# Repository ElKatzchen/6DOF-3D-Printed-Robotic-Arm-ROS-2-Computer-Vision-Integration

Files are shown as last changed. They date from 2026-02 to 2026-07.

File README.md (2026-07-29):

# 6DOF 3D-Printed Robotic Arm: ROS 2 & Computer Vision Integration

This repository contains all the necessary data to fabricate, control, and modify a **6-Degree-of-Freedom (6DOF) robotic arm**. The project combines 3D printing, advanced CAD modeling, and a distributed control system using ROS 2.

## 🚀 Overview

The system is designed for **real-time teleoperation** via computer vision. It tracks a user's hand movements in a dedicated vision area and translates those coordinates into precise robotic motion using inverse kinematics.

### Key Features:
* **Mechanical Design:** All components are 3D-printable and were fully modeled in **SolidWorks 2025**. Original design files are included for easy modification.
* **Communication Stack:** Powered by **ROS 2 Humble**, enabling seamless distributed processing between a **PC** (high-level processing) and a **Raspberry Pi** (hardware abstraction).
* **Computer Vision:** Utilizes a dual-camera setup to track hand **keypoints** (Mediapipe-based).
* **Inverse Kinematics (IK):** The system captures the $XYZ$ coordinates of the user's index finger and maps them from the "Vision Space" to the "Robot Workspace," calculating the required joint angles in real-time.

---

## 📋 Prerequisites

Before you begin, ensure you have the following software and tools installed:

### **CAD & Hardware Design**
* **SolidWorks 2025**: Required to open or modify the original `.SLDPRT` and `.SLDASM` files.
* **3D Printer Slicer**: (e.g., Ultimaker Cura or PrusaSlicer) for processing the STL files.

### **Software & Robotics OS**
* **Ubuntu 22.04 LTS**: The recommended OS for stable ROS 2 Humble integration.
* **ROS 2 Humble Hawksbill**: The primary communication middleware.
* **Python 3.10+**: For vision and kinematics scripts.

### **Computer Vision & Libraries**
To run the hand-tracking and coordinate transformation nodes, you will need:
* **OpenCV**: For image processing.
* **MediaPipe**: For hand keypoint detection and tracking.
* **NumPy**: For matrix operations and inverse kinematics calculations.

---

## 📂 Repository Structure

The repository is organized into several folders:
* `/3D-Printed_Files`: Includes STL files for printing and SolidWorks 2025 source files.
* `/Inverse_Kinematics_Codes`: Includes all necesary codes for the inverse kinematics programming.
* `/ROS2_System`: The ROS 2 workspace containing the packages for robot description and control.
* `/Vision_System`: Python scripts for dual-camera hand tracking and coordinate mapping.

---

## 🛠️ Future Work

* Add 360 degrees motors and a closed loop control system
* Integrate Move It 2
* Integrate Reinforcement Learning on the Vision System

---

## 📌 Current Status: v3.0.0
* **Current Version:** 3.0.0
* **Last Update:** June 2026
* **Stable Version:** 3.0.0

---

**Author:** [Katzchen]

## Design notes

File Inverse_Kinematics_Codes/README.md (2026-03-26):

# 📐 Inverse Kinematics & Control System

This folder contains the core logic for calculating joint angles and the communication bridge between the high-level Python processing and the low-level hardware control.

## 🧠 Kinematics Engine (Python)

The main script handles the mathematical transformation from Cartesian coordinates $(X, Y, Z)$ to joint angles $(\theta_1 ... \theta_6)$.

* **IK Solver:** A Python-based script that calculates required angles in real-time.
* **Communication:** Data is transmitted via **UART** (Serial) to the microcontroller.
* **Software Safety Layer:** The script includes a pre-transmission validation check. It prevents the system from sending commands that exceed the mechanical limits of the arm or positions that are mathematically unreachable (Singularities).

---

## 🎮 Hardware Control (ESP32 / Arduino)

The low-level control is designed for an **ESP32 (30-pin version)**. This folder includes two distinct firmware options:

### 1. Home Calibration Script (`home_setup.ino`)
A standalone script used for initial calibration. When executed, it moves all servos to their "Home" or "Rest" positions. This is essential for verifying mechanical alignment before running full autonomous control.

### 2. UART Receiver & Servo Controller (`main_controller.ino`)
This script works in tandem with the Python IK solver. It listens for incoming angle data via UART and maps it to the servo PWM signals.
* **Redundant Safety System:** To ensure system reliability, the ESP32 performs a secondary validation on all incoming data. If a received angle is outside the physical range of the motors, the command is ignored or clamped, preventing hardware damage.

---

## 🛠️ Control Workflow

1.  **Vision Input:** Hand coordinates are captured.
2.  **IK Calculation:** Python computes the angles.
3.  **Safety Check 1:** Python validates the reachable workspace.
4.  **UART Transmission:** Angles are sent to the ESP32.
5.  **Safety Check 2:** ESP32 verifies signal integrity and physical limits.
6.  **Actuation:** Servos move to the validated positions.

---

## 📌 Pinout & Hardware Notes (ESP32)
* **UART RX/TX:** Ensure common ground between the PC/Raspberry Pi and the ESP32.
* **Power Supply:** Use an external power source for the servos (don't power 7 servos directly from the ESP32). The power supply used is 5VDC 10A.

**Next Step:** For details on how the coordinates are captured, see the [**ROS2 System**](../ROS2_System) documentation.

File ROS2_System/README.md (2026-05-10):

# 🤖 ROS 2 Workspace: Distributed Control System

This folder contains the **ROS 2 Humble** packages and nodes that manage communication, image streaming, and coordinate processing between the **Raspberry Pi** and the **Workstation (PC)**.

## 🏗️ System Architecture

The project follows a distributed architecture with **4 main nodes** designed to minimize latency and optimize processing power:

### 📡 Raspberry Pi Nodes (Edge)
* **Camera Publishers (2 Nodes):** These nodes capture real-time video streams from the dual-camera setup and publish them as compressed image topics to the network.
* **Servo Subscriber (1 Node):** This node listens for the calculated joint angles sent from the PC. Once received, it forwards the data via **UART** to the ESP32 microcontroller for physical actuation.

### 🖥️ Workstation Node (Central Processing)
* **Vision & IK Processor (1 Publisher/Subscriber Node):** This is the "brain" of the ROS 2 network.
    * **Subscribes** to the raw image topics from the Raspberry Pi.
    * **Processes** the images to extract hand keypoints and XYZ coordinates.
    * **Calculates** the Inverse Kinematics (IK) to determine the required servo angles.
    * **Publishes** the final angles back to the Raspberry Pi.

---

## 🔄 Data Flow (DDS Pipeline)

1.  **[RPI]** Camera Nodes ➔ `sensor_msgs/CompressedImage`
2.  **[PC]** Vision Node ➔ Hand Tracking ➔ IK Calculation
3.  **[PC]** Vision Node ➔ `std_msgs/Float64MultiArray` (Servo Angles)
4.  **[RPI]** Subscriber Node ➔ Serial/UART ➔ **ESP32**

---

## 🛠️ Installation & Setup

### **Build Instructions**
Navigate to the root of your workspace and run:
```bash
colcon build --symlink-install
source install/setup.bash

**Next Step:** For details on how the coordinates artificail system works, see [**Vision System**](../Vision_System) documentation.

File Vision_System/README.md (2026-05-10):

# 👁️ Computer Vision & Spatial Mapping System

This folder contains the core logic for dual-camera hand tracking, coordinate mapping, and the distributed ROS 2 pipeline. It is divided into three specialized submodules.

---

## 🛠️ 1. Camera Calibration (`/calibration`)
Before operation, the cameras must be intrinsically calibrated to ensure spatial accuracy.
* **Process:** Take 25 photos of a chessboard pattern from different angles.
* **Default Pattern:** 10x7 squares, with a square size of **26mm** (adjustable in the script).
* **Output:** Generates `.npz` files containing the camera matrices and distortion coefficients.

---

## 🖥️ 2. Workstation Logic (`/Vision_System_Computer`)
This is the central processing unit of the vision system. It runs a **Publisher/Subscriber** node that performs the following:

1. **Data Acquisition:** Subscribes to `/cam_sup` and `/cam_side` image topics.
2. **Keypoint Detection:** Uses an AI-based system to detect hand keypoints:
    * **Index Finger:** Determines the target **$XYZ$ coordinates**.
    * **Middle Finger:** Acts as a trigger for the **gripper** (open/close logic).
3. **Processing Pipeline:** The coordinates are pre-processed and fed into the **Inverse Kinematics (IK)** function to calculate the 7 required servo angles.
4. **Broadcast:** Sends the final joint array to the subscriber node.

---

## 🍓 3. Edge Processing (`/Vision_System_RPI`)
Managed via the Raspberry Pi, this module handles hardware-level communication.

* **Nodes:**
    * **2x Publishers:** One for each camera stream.
    * **1x Subscriber:** Receives 7 angles at a frequency of **5Hz** (5 times/sec) to filter noise and ensure stable movement.
* **Hardware Interface:** Forwards the validated data via **UART** to the ESP32.

### 🐳 Docker Deployment (RPI)
The RPI environment is containerized for consistency. To deploy:

```bash
docker compose down
docker compose up -d
docker compose exec ros2_env bash
```

Once inside the Docker bash terminal, initialize the workspace:
```bash
source /opt/ros/humble/setup.bash
colcon build
source install/setup.bash
```
### 🌐 Network Configuration
To enable communication between the Computer and the RPI, set the ROS_DOMAIN_ID on both devices:
```bash
export ROS_DOMAIN_ID=0
echo $ROS_DOMAIN_ID
```

Additionally, on the Raspberry Pi terminal, export its IP address (must match your mobile hotspot IP):
```bash
export ROS_IP=192.168.X.X
```

#### 📦 Dependencies & Troubleshooting
1. **Serial Communication:** Install the necessary library for UART inside the Docker container:
    ```bash
    apt-get update && apt-get install -y python3-serial
    ```
2. **MediaPipe & Conda Integration:** If you encounter compatibility issues between MediaPipe and ROS 2, run ROS 2 within your Conda environment and manually link the site-packages:
    ```bash
    export PYTHONPATH=$PYTHONPATH:/home/katzchen/miniconda3/envs/taller/lib/python3.10/site-packages
    ```
3. **Hardware Verification:** To verify camera detection on the RPI, use:
    ```bash
    v4l2-ctl --list-devices
    ```

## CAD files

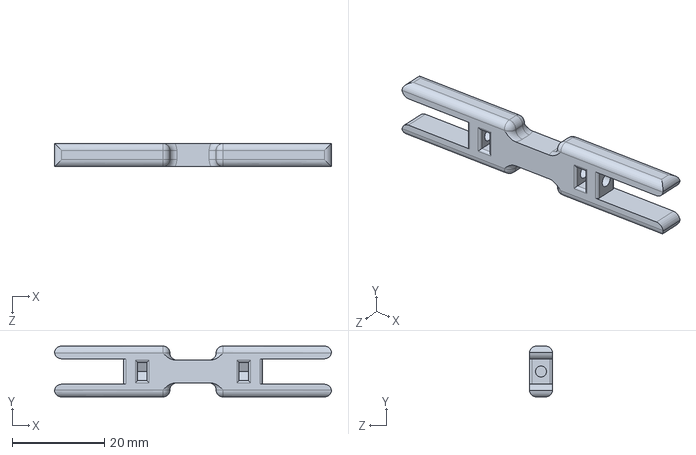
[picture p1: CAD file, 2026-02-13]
3D-Printed_Files/Camera/Pieces/Frame_side.SLDPRT
60.0 x 11.0 x 5.00 mm

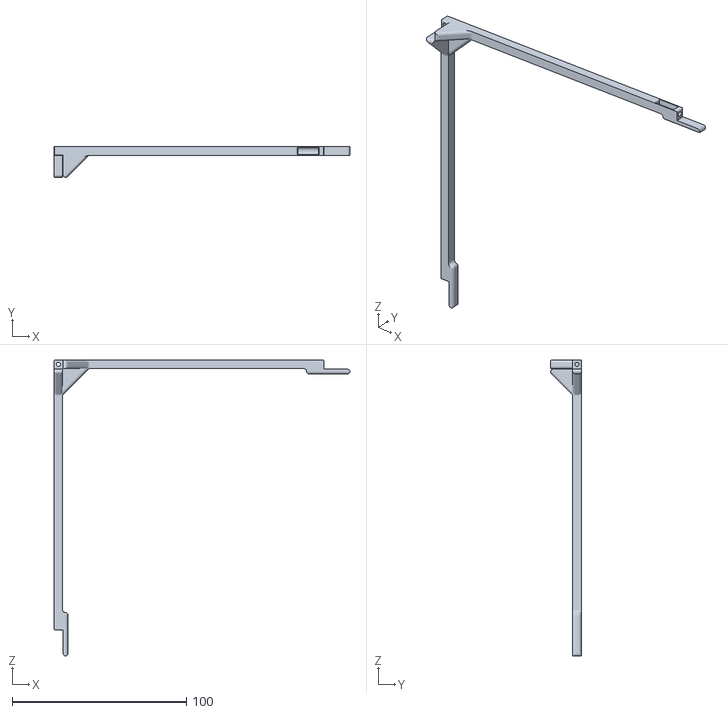
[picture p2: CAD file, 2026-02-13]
3D-Printed_Files/Camera/STLs/Frame_corner.STL
170.0 x 17.6 x 170.0

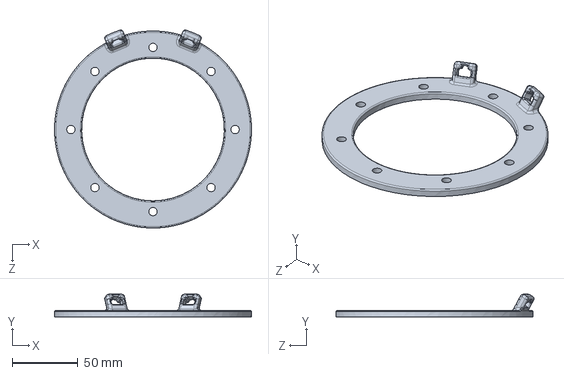
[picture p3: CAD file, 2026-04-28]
3D-Printed_Files/ES08MA_II/Pieces/Wire_Holder.SLDPRT
149.9 x 17.4 x 150.8 mm

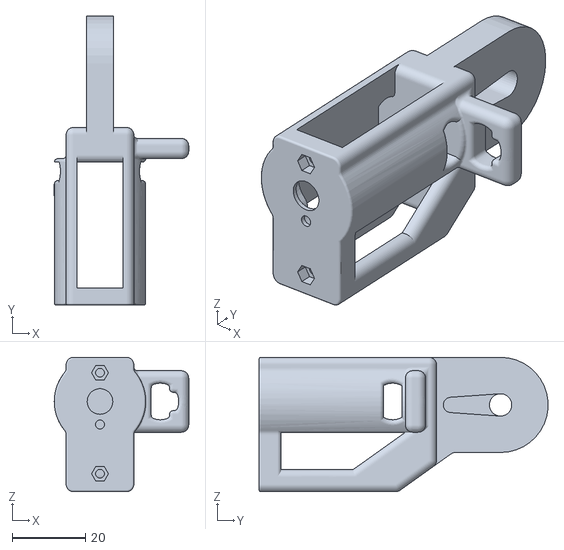
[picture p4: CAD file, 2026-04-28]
3D-Printed_Files/ES08MA_II/STLs/Arm_1st_Joint.STL
36.8 x 79.0 x 36.7

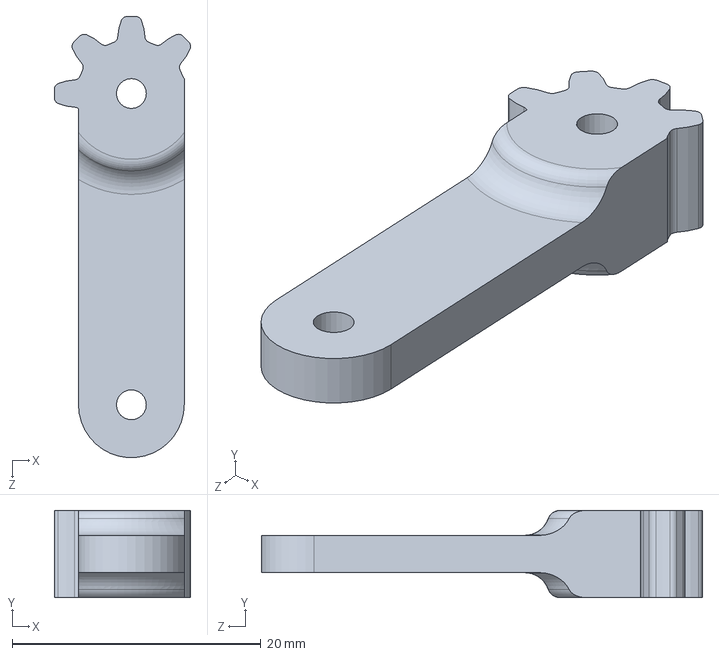
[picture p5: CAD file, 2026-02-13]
3D-Printed_Files/SG90S/Pieces/Claw_Gear_Joint.SLDPRT
11.0 x 7.00 x 35.4 mm

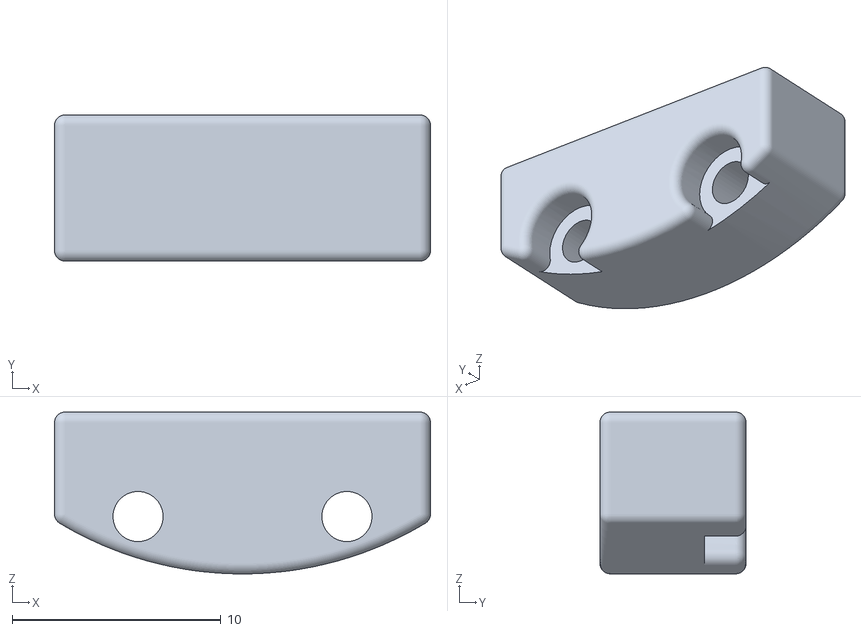
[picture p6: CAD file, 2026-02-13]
3D-Printed_Files/SG90S/STLs/Holder_MG996R_Upper.STL
18.0 x 7.00 x 7.75

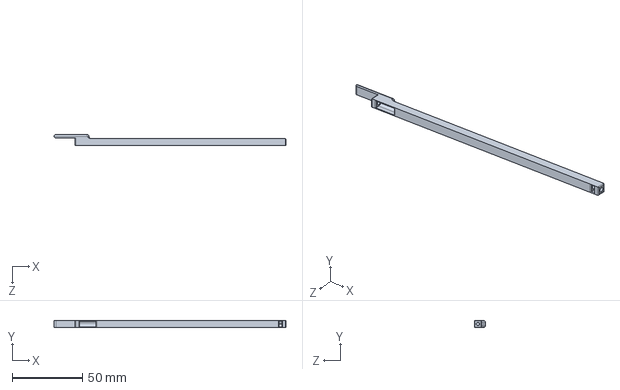
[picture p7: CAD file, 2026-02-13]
3D-Printed_Files/Camera/Pieces/Frame_corner_zax.SLDPRT
165.0 x 5.00 x 8.00 mm

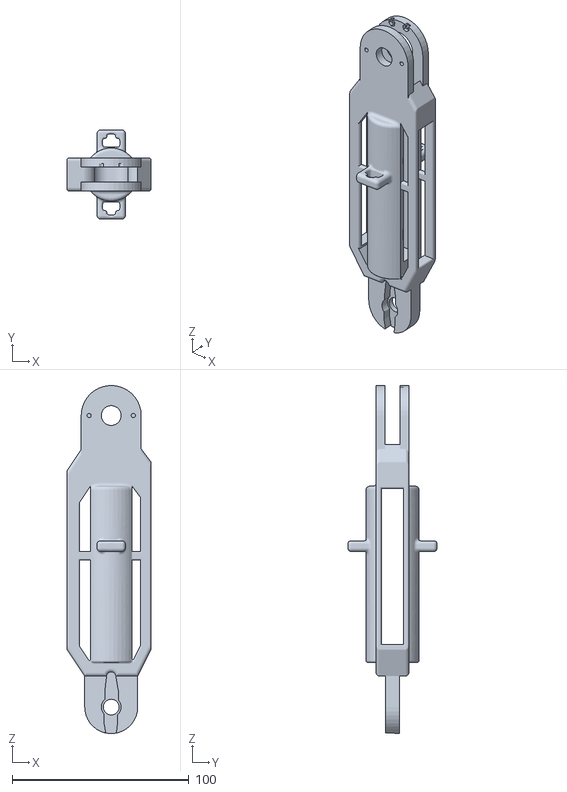
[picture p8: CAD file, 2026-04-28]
3D-Printed_Files/ES08MA_II/STLs/Arm_4th_Joint.STL
47.5 x 50.5 x 196.9

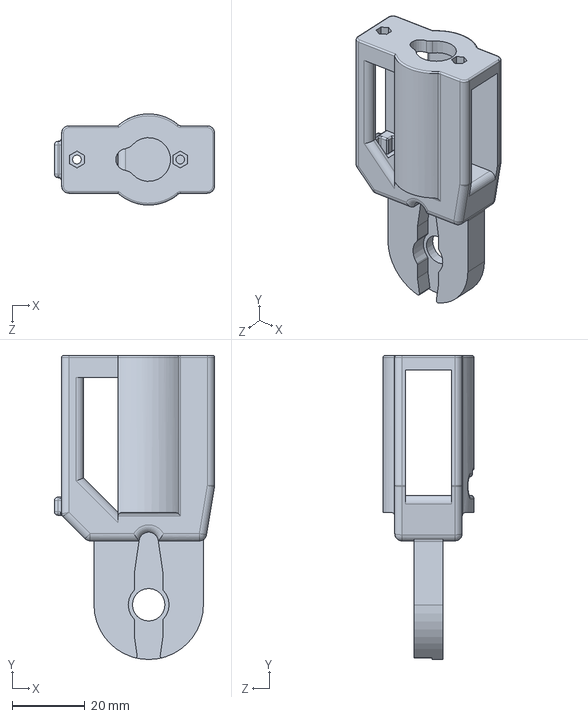
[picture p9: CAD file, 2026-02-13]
3D-Printed_Files/SG90S/Pieces/Arm_3rd_Joint.SLDPRT
43.9 x 83.3 x 25.0 mm

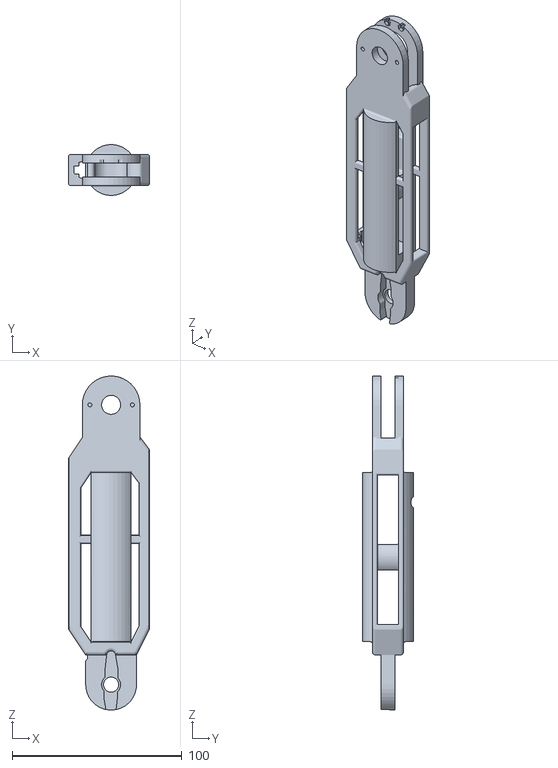
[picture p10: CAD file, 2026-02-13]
3D-Printed_Files/SG90S/STLs/Arm_4th_Joint.STL
47.5 x 29.9 x 196.9

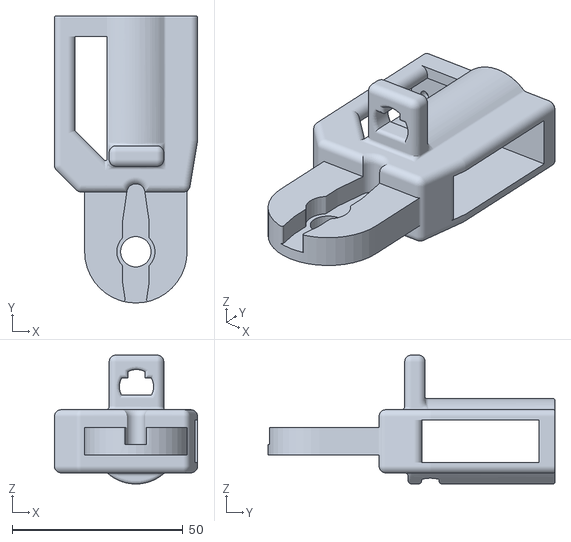
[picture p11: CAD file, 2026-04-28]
3D-Printed_Files/ES08MA_II/STLs/Arm_3rd_Joint.STL
41.9 x 84.0 x 37.8

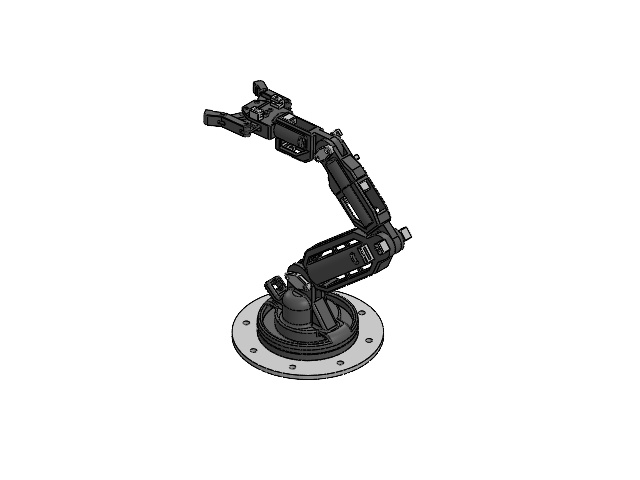
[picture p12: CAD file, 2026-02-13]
3D-Printed_Files/SG90S/Pieces/Assembly.SLDASM
Claw_Arm x 2
Claw_Base
Claw_Finger_Left
Claw_Finger_Right
Gear_Arm
Gear_Motor_Arm
Forearm
Arm_Forearm
Arm_Forearm_Center
Arm_Holders x 9
Arm_Holder_Mini x 3
Rotor_Holder
Arm_Base
Base
Base_Rotor
Base_Box
Base_Motor_Holder_Inferior x 4
Base_Motor_Holder_Superior x 4
Base_Rotor_Holder

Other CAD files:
3D-Printed_Files/Camera/STLs/Frame_corner_z_axis.STL
3D-Printed_Files/ES08MA_II/Pieces/Arm_1st_Joint.SLDPRT
3D-Printed_Files/Camera/Pieces/Frame_corner.SLDPRT
3D-Printed_Files/Camera/STLs/Frame_side.STL
3D-Printed_Files/ES08MA_II/Pieces/Arm_4th_Joint.SLDPRT
3D-Printed_Files/ES08MA_II/Pieces/Arm_2nd_Joint.SLDPRT
3D-Printed_Files/ES08MA_II/Pieces/Arm_3rd_Joint.SLDPRT
3D-Printed_Files/ES08MA_II/Pieces/Base_Arm_Joint.SLDPRT
3D-Printed_Files/ES08MA_II/Pieces/Base_Box_Joint.SLDPRT
3D-Printed_Files/ES08MA_II/Pieces/Base_Rotor_Plate.SLDPRT
3D-Printed_Files/ES08MA_II/Pieces/Claw_Finger_Left.SLDPRT
3D-Printed_Files/ES08MA_II/Pieces/Claw_Finger_Right.SLDPRT
3D-Printed_Files/ES08MA_II/Pieces/Claw_Gear_Joint.SLDPRT
3D-Printed_Files/ES08MA_II/Pieces/Claw_Gear_Motor_Joint.SLDPRT
3D-Printed_Files/ES08MA_II/Pieces/Claw_Hand.SLDPRT
3D-Printed_Files/ES08MA_II/Pieces/Claw_Joint.SLDPRT
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

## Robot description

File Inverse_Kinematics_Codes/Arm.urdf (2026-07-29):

<?xml version="1.0"?>
<robot name="Robotic_Arm_6dof">
  <link name="base_link"/>
  
  <link name="link1"/>
  <joint name="joint1" type="revolute">
    <parent link="base_link"/><child link="link1"/>
    <origin xyz="0 0 68" rpy="0 0 0"/><axis xyz="0 0 1"/>
    <limit lower="-1.309" upper="1.309" effort="10" velocity="1"/>
  </joint>

  <link name="link2"/>
  <joint name="joint2" type="revolute">
    <parent link="link1"/><child link="link2"/>
    <origin xyz="0 0 0" rpy="0 0 0"/><axis xyz="0 1 0"/>
    <limit lower="-1.222" upper="1.222" effort="10" velocity="1"/>
  </joint>

  <link name="link3"/>
  <joint name="joint3" type="revolute">
    <parent link="link2"/><child link="link3"/>
    <origin xyz="0 0 165" rpy="0 0 0"/><axis xyz="0 1 0"/>
    <limit lower="-1.309" upper="1.309" effort="10" velocity="1"/>
  </joint>

  <link name="link4"/>
  <joint name="joint4" type="revolute">
    <parent link="link3"/><child link="link4"/>
    <origin xyz="0 0 109" rpy="0 0 0"/><axis xyz="0 0 1"/>
    <limit lower="-1.222" upper="1.222" effort="10" velocity="1"/>
  </joint>

  <link name="link5"/>
  <joint name="joint5" type="revolute">
    <parent link="link4"/><child link="link5"/>
    <origin xyz="0 0 0" rpy="0 0 0"/><axis xyz="0 1 0"/>
    <limit lower="-1.222" upper="1.222" effort="10" velocity="1"/>
  </joint>

  <link name="end_effector"/>
  <joint name="joint6" type="revolute">
    <parent link="link5"/><child link="end_effector"/>
    <origin xyz="0 0 150" rpy="0 0 0"/><axis xyz="0 0 1"/>
    <limit lower="-1.309" upper="1.309" effort="10" velocity="1"/>
  </joint>
</robot>

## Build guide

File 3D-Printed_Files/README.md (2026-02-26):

# 🏗️ Hardware & CAD Models

This section contains all the **SolidWorks 2025** source files and **STL** files required to fabricate the 6DOF robotic arm and the computer vision frame.

## 📂 Folder Structure

The hardware files are organized into three main categories to facilitate navigation:

1. **Vision Frame:** Contains the 3 components required to assemble the physical structure for the dual-camera setup.
2. **Arm - Version A (SG90S + MG996R):** Optimized for standard SG90S micro servos and MG996R metal gear motors.
3. **Arm - Version B (ES08MA II + MG996R):** Optimized for Emax ES08MA II high-torque micro servos and MG996R motors.

> **Note:** If you do not wish to modify the designs, pre-exported files are available in the **STLs** folder within each category for direct 3D printing.

---

## 🔩 Technical Specifications

### **Hardware & Fasteners**
To ensure structural integrity, the design uses specific bolt sizes:
* **Main Joints:** Designed for **M2 bolts**.
* **Base Assembly:** Designed for **M6 bolts** to provide a stable foundation.

### **Component Naming Convention**
Files are prefixed based on their function to simplify the assembly process:
* `Claw_`: End effector and gripper components.
* `Arm_`: Main structural segments and linkages.
* `Base_`: Rotating foundation and main axis.
* `Holder_`: Reinforced supports for critical sections and motor mounting.

### **Actuators (Motors)**
To fully assemble one arm, you will need the following servos:
* **4x** Micro Servos (either **SG90S** or **ES08MA II**, depending on your chosen version).
* **3x** **MG996R** High-Torque Metal Gear Servos.

### **Vision Area**
* The vision frame is precisely calibrated to delimit a workspace of **$33 \times 33 \times 33$ cm**.

---

## 🖨️ 3D Printing Recommendations

For best results and mechanical strength, the following settings are suggested:

* **Material:** PLA+ or PETG (for better impact resistance).
* **Infill:** 5-15% (Gyroid pattern) for arm segments.
* **Wall Count:** Minimum of 3-4 wall lines for all load-bearing parts.
* **Supports & Bed Adhesion:**
    * **Full Support Required:** It is highly recommended to use supports for all parts.
    * **3mm Offset:** All pieces should be printed with a **3mm support base/offset from the heat bed**. This prevents bottom-layer deformation (elephant's foot) and ensures that all mechanical dimensions remain accurate and consistent across the entire part.
    
---

**Next Step:** Once printed, proceed to the [**Inverse Kinematics**](../Inverse_Kinematics_Codes) folder for assembly and motor calibration instructions.

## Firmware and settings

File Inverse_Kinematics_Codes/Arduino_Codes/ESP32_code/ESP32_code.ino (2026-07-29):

#include <ESP32Servo.h>

const int NumServos = 7;
Servo Servos[NumServos];
int PinServos[] = {32, 33, 25, 19, 18, 5, 27};

int MinLim[] = {30, 10, 10, 10, 5, 5, 5}; 
int MaxLim[] = {90, 170, 170, 150, 175, 175, 165};
int Home[] = {90, 90, 150, 80, 150, 50, 85};

int g_grip_actual, g_grip_target; 
int g_s1, g_s2, g_s3, g_s4, g_s5, g_s6;

const int Samples = 5;
int Buffer[7][Samples];
int Indice = 0;

unsigned long lastGripTime = 0;
const long gripInterval = 200;

int PromCalculus(int servoIdx, int nuevoValor) {
  Buffer[servoIdx][Indice] = nuevoValor;
  long suma = 0;
  for (int i = 0; i < Samples; i++) {
    suma += Buffer[servoIdx][i];
  }
  return suma / Samples;
}

void setup() {
  Serial.begin(115200);
  delay(1000);
  
  ESP32PWM::allocateTimer(0);
  ESP32PWM::allocateTimer(1);
  ESP32PWM::allocateTimer(2);
  ESP32PWM::allocateTimer(3);

  for (int i = 0; i < NumServos; i++) {
    Servos[i].setPeriodHertz(50);
    Servos[i].write(Home[i]);
    Servos[i].attach(PinServos[i], 500, 2400);
    for(int j = 0; j < Samples; j++) Buffer[i][j] = Home[i];
  }
  g_grip_actual = Home[0];
  g_grip_target = Home[0];
}

void loop() {
  if (millis() - lastGripTime >= gripInterval) {
    if (g_grip_actual != g_grip_target) {
      if (g_grip_actual < g_grip_target) g_grip_actual += 5;
      else g_grip_actual -= 5;
      
      g_grip_actual = constrain(g_grip_actual, MinLim[0], MaxLim[0]);
      Servos[0].write(g_grip_actual);
    }
    lastGripTime = millis();
  }

  if (Serial.available() > 0) {
    if (Serial.peek() == '$') {
      Serial.read();
      String data = Serial.readStringUntil('\n');
      data.trim();
      
      if (data.length() < 15) return;

      int values[7];
      int DataCount = 0;
      int startIndex = 0;
      int endIndex;

      while ((endIndex = data.indexOf('/', startIndex)) != -1) {
        if (DataCount < 7) values[DataCount++] = data.substring(startIndex, endIndex).toInt();
        startIndex = endIndex + 1;
      }
      if (DataCount < 7) values[DataCount++] = data.substring(startIndex).toInt();

      if (DataCount >= 7) {
        // Gripper: sin filtro, va directo al target para la rampa
        g_grip_target = constrain(values[0], MinLim[0], MaxLim[0]);
        
        // Servos 1-6: aplican el filtro de media móvil
        g_s1 = PromCalculus(1, constrain(values[1], MinLim[1], MaxLim[1]));
        g_s2 = PromCalculus(2, constrain(values[2], MinLim[2], MaxLim[2]));
        g_s3 = PromCalculus(3, constrain(values[3], MinLim[3], MaxLim[3]));
        g_s4 = PromCalculus(4, constrain(values[4], MinLim[4], MaxLim[4]));
        g_s5 = PromCalculus(5, constrain(values[5], MinLim[5], MaxLim[5]));
        g_s6 = PromCalculus(6, constrain(values[6], MinLim[6], MaxLim[6]));

        Servos[1].write(g_s1);
        Servos[2].write(g_s2);
        Servos[3].write(g_s3);
        Servos[4].write(g_s4);
        Servos[5].write(g_s5);
        Servos[6].write(g_s6);
        
        Indice = (Indice + 1) % Samples;
      }
    } else {
      Serial.read();
    }
  }
}

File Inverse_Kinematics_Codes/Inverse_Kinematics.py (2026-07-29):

import math
import serial
import time
import numpy as np
from ikpy.chain import Chain

#----------CONFIGURACIÓN IKPY----------
# Asegúrate de que Arm.urdf esté en la misma carpeta que este script
chain = Chain.from_urdf_file("Arm.urdf", active_links_mask=[False, True, True, True, True, True, True])
limits = [
    [-1.309, 1.309], [-1.222, 1.222], [-1.309, 1.309], 
    [-1.222, 1.222], [-1.222, 1.222], [-1.309, 1.309]
]
target_vector = [1, 0, -1]

def calcular_cinematica(target_xyz, chain, limits, target_vector):
    try:
        # Cálculo de cinemática inversa
        angles = chain.inverse_kinematics(
            target_position=target_xyz, 
            target_orientation=target_vector, 
            orientation_mode="Z"
        )
        
        # Procesamiento de ángulos
        raw_angles = angles[1:]
        restricted_angles = [np.clip(raw_angles[i], limits[i][0], limits[i][1]) for i in range(len(raw_angles))]
        
        # Inversión de orden (de punta a base)
        inverted_angles = restricted_angles[::-1]
        
        # Conversión a grados y aplicación de offsets
        degrees = np.degrees(inverted_angles)
        offsets = np.array([85, 80, 80, 80, 75, 80])
        result = degrees + offsets
        
        # Retorno como enteros
        return result.astype(int)
    except Exception as e:
        print(f"CALCULATION ERROR: {e}")
        return None

#-----LOOP PRINCIPAL-----
try:
    esp32 = serial.Serial('/dev/ttyUSB0', 115200, timeout=0.1)
    time.sleep(3)
    print("SYSTEM READY (IKPY MODE)")

    while True:
        input_coords = input("\nCOORDS X, Y, Z (Enteros): ")
        if input_coords.lower() == 'x': break
        try:
            parts = [v.strip() for v in input_coords.split(',')]
            # Convertimos las coordenadas directamente a enteros
            x, y, z = map(int, parts)
            
            # Llamada a la función de cinemática
            res = calcular_cinematica([x, y, z], chain, limits, target_vector)
            
            if res is not None:
                # Formato de envío: [90, Servo1, Servo2, Servo3, Servo4, Servo5, Servo6]
                full_vals = [150] + list(res) 
                payload = "$" + "/".join([f"{int(v):03d}" for v in full_vals]) + "\n"
                
                esp32.reset_input_buffer()
                esp32.write(payload.encode())
                print(f"SEND -> {payload.strip()}")

                time.sleep(0.05)
                if esp32.in_waiting > 0:
                    feedback = esp32.readline().decode('utf-8').strip()
                    print(f"FEEDBACK -> {feedback}")
            else:
                print("ALERT: IMPOSSIBLE POSITION")
        except Exception as e:
            print(f"ERROR: {e}")
finally:
    if 'esp32' in locals(): 
        esp32.close()

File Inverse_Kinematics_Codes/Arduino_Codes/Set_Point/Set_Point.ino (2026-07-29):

#include <ESP32Servo.h>
//GRIPPER 90---150 open-close
//JOINT 1 85+-75 ccw-cw
//JOINT 2 80+-70 up-down
//JOINT 3 80+-70 ccw-cw
//JOINT 4 80+-75 up-down
//JOINT 5 75+-70 up-down
//JOINT 6 80+-75 ccw-cw

const int NumServos = 7;
Servo Servos[NumServos];

// GPIO 32, 33, 25, 19, 18, 5, 27
int PinServos[] = {32, 33, 25, 19, 18, 5, 27};

//-----SERVOS SETTING-----
//Change this to the default setting for the servos
//int Set[] = {90, 85, 150, 80, 150, 45, 85};
//This to position teh arm completly straight
int Set[] = {30, 85, 80, 80, 80, 80, 85};

void setup()
{
  ESP32PWM::allocateTimer(0);
  ESP32PWM::allocateTimer(1);
  ESP32PWM::allocateTimer(2);
  ESP32PWM::allocateTimer(3);

  for (int i = 0; i < NumServos; i++)
  {
    Servos[i].setPeriodHertz(50);
    Servos[i].attach(PinServos[i], 500, 2400); 
    Servos[i].write(Set[i]);
  }
}

void loop()
{
  delay(1000); 
}

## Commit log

2026-02-13 3D pieces added
    [Arm_Base.SLDPRT, Arm_Base.STL, Arm_Forearm.SLDPRT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]
2026-02-14 Claw and camera pieces renamed
    [Base.SLDPRT, Base.STL, Claw_Gear_Joint.SLDPRT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]
2026-02-14 Arm pieces names fixed
    [Arm_1st_Joint.SLDPRT, Arm_1st_Joint.STL, Arm_2nd_Joint.SLDPRT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]
2026-02-15 Base pieces names fixed
    [Base_Arm_Joint.SLDPRT, Base_Arm_Joint.STL, Base_Box_Joint.SLDPRT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]
2026-02-15 Holders pieces names fixed
    [Holder_ES08MA_II_Rotor.SLDPRT, Holder_ES08MA_II_Rotor.STL, Holder_ES08MA_II_T1.SLDPRT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]
2026-02-15 Base readme added
    [Arm_1st_Joint.SLDPRT, Arm_1st_Joint.STL, Arm_2nd_Joint.SLDPRT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]
2026-02-26 Inverse Kinematics codes added
2026-03-10 YPR added and reach corrected
    [ESP32_code.ino, Inverse_Kinematics.py, Set_Point.ino]
2026-04-28 New STL models uploaded
    [Arm_1st_Joint.SLDPRT, Arm_1st_Joint.STL, Arm_2nd_Joint.SLDPRT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]
2026-05-02 DH with ESP32 working // Minor fixes in ROS2 // Arduino code constrains added
    [ESP32_code.ino, IK_DH_Matrix.py, Set_Point.ino]
2026-05-05 Calibration code added // Sub node added
2026-05-06 Publicators added and fixed
    [pubside.py, pubsup.py, sub.py]
2026-07-29 Stable version uploaded. Working system fully uploaded
    [Arm copy.urdf, Arm.urdf]
